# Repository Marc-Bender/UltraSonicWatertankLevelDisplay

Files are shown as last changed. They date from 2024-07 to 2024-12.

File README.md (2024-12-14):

# README

##Intended Usecase
Waterlevel display in multitank battey of tanks. Tanks are located in basement, sense device will be mounted on top of tanks far enough away from filling port. 
Thus no watertightness or waterresistance is implemented for any of the components.

## Design Features
Multiple Sensorboards "supported" by design (read Mistakes#J5 for more).
Elaborate Liter-age estimation algorithm by approximation of tank geometry with multiple boxes of varying area, spacing of estimation-box-area-entries parametrizable (1 global value)
Remaining Tankgeometry (Distance when full, distance when empty, number of tanks) parametrizable. 
Measurement sample averaging with parametrizable sample count for general stability, reproducability and compensation of effects of surface-waves while filling (effectiveness not proven)
Sleep modes for powersaving: between user interactions (deepest possible sleep mode), for time that display is supposed to be on (deepest sleep mode that can be left by timer)
Parametrization via UART with ready made tool (Open protocol)

## Operating instructions
Connect battery without pressing the front panel button --> normal startup procedure; system will perform one measurement cycle and show the results on the display
Connect battery with pressed front panel button --> boot into parametrization mode; leave via UART command or powercycle

## Basic-most Troubleshooting 
### "Display stays dark on button press"
Disassembly of sense device, check battery voltage -- system will not attempt any measurements below 7V
When Battery Voltage >7V attempt powercycle (battery disconnect-reconnect)

## Parametrization protocol
### UART Specifics
9600Baud, 8bits, 1 stop bit, no parity
### Leaving the parametrization session
send ":q" (without quotes)
### write a memory location 
send ":wXXYY" where XX is the address in MSB first and YY is the value in MSB first (both 16bit); device will respond with ":WXX00" where XX is that same address and 00 is padding data.
### read a memory location
analogous to write except ":r" is to be used instead of ":w"; data will be in last two response bytes in 16bit MSBFirst
### Memory Map
TankFullCM         | 0x0000 | 2bytes
TankEmptyCM        | 0x0002 | 2bytes
NumTanks           | 0x0004 | 1byte
AreaEntryCount     | 0x0005 | 1byte
AreaEntrySpacingCm | 0x0006 | 1byte
AveragingCount     | 0x0007 | 1byte
SensorType         | 0x0008 | 1byte (0: HC-SR04, 1:Grove)
AreaEntrySpaceStart| 0x000A | 2bytes per entry

## Power Figures
To be powered from a 9V Block Battery. Active current (w/ Display on, sensor not attached) is ~15mA. 
The MCU will be in sleep just about the entire time. The current transient for the MCU being active is assumed to be neglegdable.
The current transient by the sensor has not been determined. But the sensor is powered from IO Pins and normally unpowered thus not adding to the Iq.
The current consumption in sleep (Display off, sensor disconnected, MCU sleep) was in the noise of the multimeter (readings are typical at ~1mV across 10R shunt experimentally put in place instead of regulator; ~100uA)

## Hacking features
Default values for liter estimation algorithm when activated by define but not configured in EEPROM.
Define for circumventing the Battery voltage measurement evaluation -- effectively rendering the BatteryLowFault State inoperable/unreachable.

## Mistakes 

### Parametrization tool 

Somehow the parametrization did not work in the real usecase where the device is powered from a 9V battery; neither with connected gnd nor with connected 5V rail nor both connected (to the usb to serial brigde)
Parametrization also did not work no matter if the TX and RX lines are crossed or not. -- I did not feel like investing any time in this issue anymore, thus did not use the parametrization at all and hardcoded the tank geometry
Circumvent: recompile firmware with different values for each tank geometry or manually generate the eeprom file. 

### voltage measurement 

The battery voltage measurement is wildly off -- this may be down to the reference of the ADC (VCCA) not being measured in any way impacting the measured value...
Circumvent: none

### case design / Assembly design 

the screw holes for the display retainment screws should not have gone through the entire part. 
the Controller PCB should have had any mounting holes. 
The PCB Sandwich should be held in place on the button side as well in some way; solved by drilling through the PCB (somewhere in the gnd plane above the button) and into the frontplate then securing the pcb sandwich with 1 or 2 threads of a screw
The button actuator may collide with the PCB sandwich and should be reshaped.
The Parametrization header's 5V pin is obscured by the lower mounting hole of the display -> circumvent by snipping that off.

### Q5
Reverse voltage Protection "Diode" Transistor (Q5) did not work in my testing.
Circumvent by placing a ordinary diode between pins 1 and 2 of the footprint.

### U2
Was not available to me at the time of building and pinning is unlike 117 or 78xx series regulator thus the device may be a bad pick when a generic jellybean part would be wanted. 
There is no special reason to use this one. 
Circumvent by either buying appropriate part or replace with 7805 mounted in reverse (smaller footprint one will work as current consumption of MCU and display when active is ~15mA in my measurement thus anysize regulator will likely be enough)

### J1
/tRST is connected to MCU but /sRST would be the one to use with standard AVR JTAG pinout. 
Circumvent by either using SPI which is available on the Display header or by shorting the /tRST and /sRST pins together.

### U1
ATmega1284P was initially designed in as it happened to be in my junkbox... later replaced with ATmega324PB as a cheaper more than plenty replacement.
The ATmega324PB is not exactly pin compatible as the two (1284P) supply pins on the bottom edge (17, 18) are IO pins on the 324PB.
Circumvent: none
Fix: new layout or stick with original design MCU. 
Impact: none as long as the SW does not configure the two pins as outputs (which it should not -- by design)

### V0
V0 had been planned to be connected to resistor divider for contrast setting (that is switch-off-able). But fixed 1k pull down would be enough.
Circumvent by not placing R13, R14, R11, Q3 and instead placing R12 as ~500R and placing another ~500R between pins 2 and 3 of Q3 (slight cant).
alternatively only place R12 as 1k and bridge pins 2 and 3 of Q3

### J5 
Pinning of header for Grove Ultrasonic rangefinder module is completely messed up w/ regard to the module. 
Circumvent: use a crossover wireharnes and / or change the pinning in as far as possible (supply pins). Possibly bridge pin 3 and 4 on J5 to fix switched signal and NC pin. 
alternatively stick with HC-SR04 board instead. 
Firmware side of things has not been verified for Grove module at all thus it may require some hacking to get working. 

### Q4 
Technically working how ever not sufficent for turning off the display. The display module will get its power also over the data and control lines if not powered thus setting all data and control lines to input-no-pullup before turning off the display is required.
Circumvent: not needed -- already accounted for in Firmware. 

## Issues
### Parametrization tool communication (General)
Send commands multiple times until a) the display lights up [stop session command] or b) message counter in log window in bottom updates
### Parametrization tool connection
Start the sense device in parametrization mode.
Send the stop command from the tool until successfully left the session. 
Keep the Tool running and connected to the UART to USB adapter.
Restart the sense device in parametrization mode. 
The communciation should now work -- signs of a non working communication are UI buttons not changing their animated state.
### Parametrization best practices
Send a value
set a different value
Read back value --> the UI element for setting doubles for display and should change value to before set value.

Always leave the parametrization session by stop command when values have been changed in order for the write to peristant memory to happen.

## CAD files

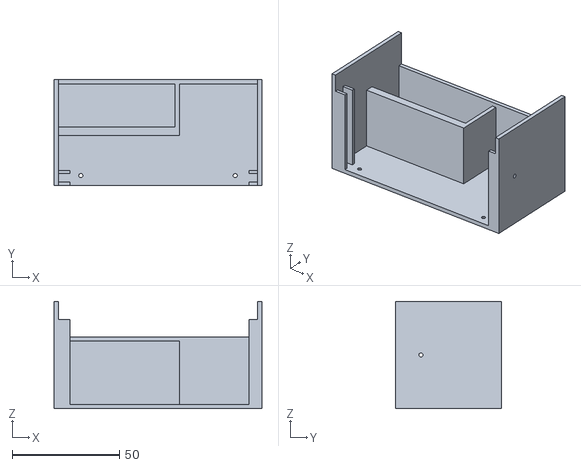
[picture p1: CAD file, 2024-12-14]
Mechanical Development/Box Upper.stl
97.0 x 49.2 x 50.0

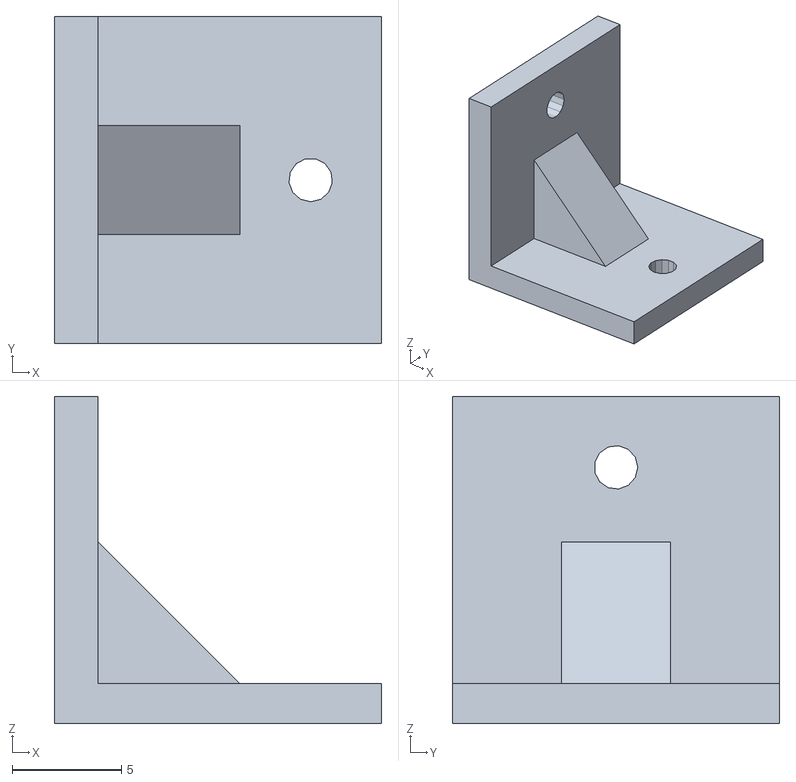
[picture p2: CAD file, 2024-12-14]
Mechanical Development/Bracket.stl
15.0 x 15.0 x 15.0

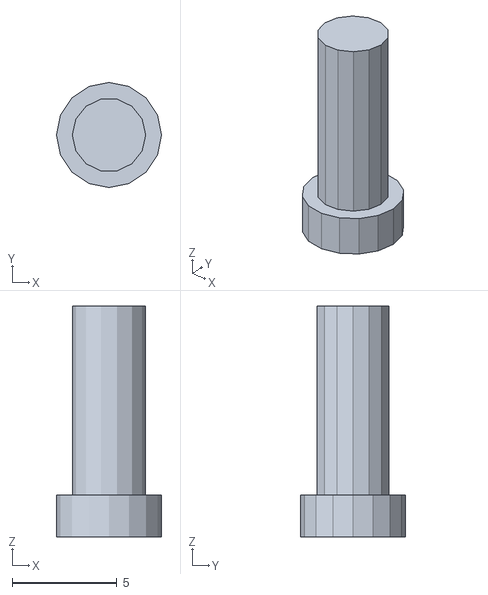
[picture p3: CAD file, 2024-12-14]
Mechanical Development/Drücker.stl
5.00 x 5.00 x 11.0

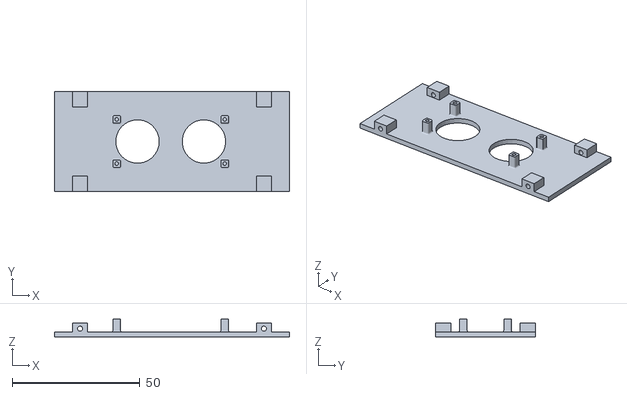
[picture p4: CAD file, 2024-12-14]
Mechanical Development/Box Lower.stl
92.0 x 39.0 x 7.00

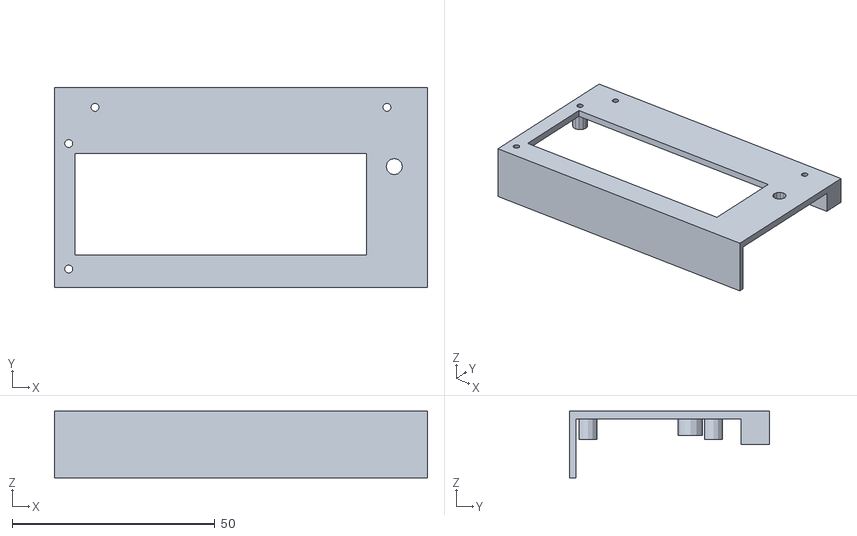
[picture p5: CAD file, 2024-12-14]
Mechanical Development/Frontplate.stl
92.0 x 49.2 x 16.5

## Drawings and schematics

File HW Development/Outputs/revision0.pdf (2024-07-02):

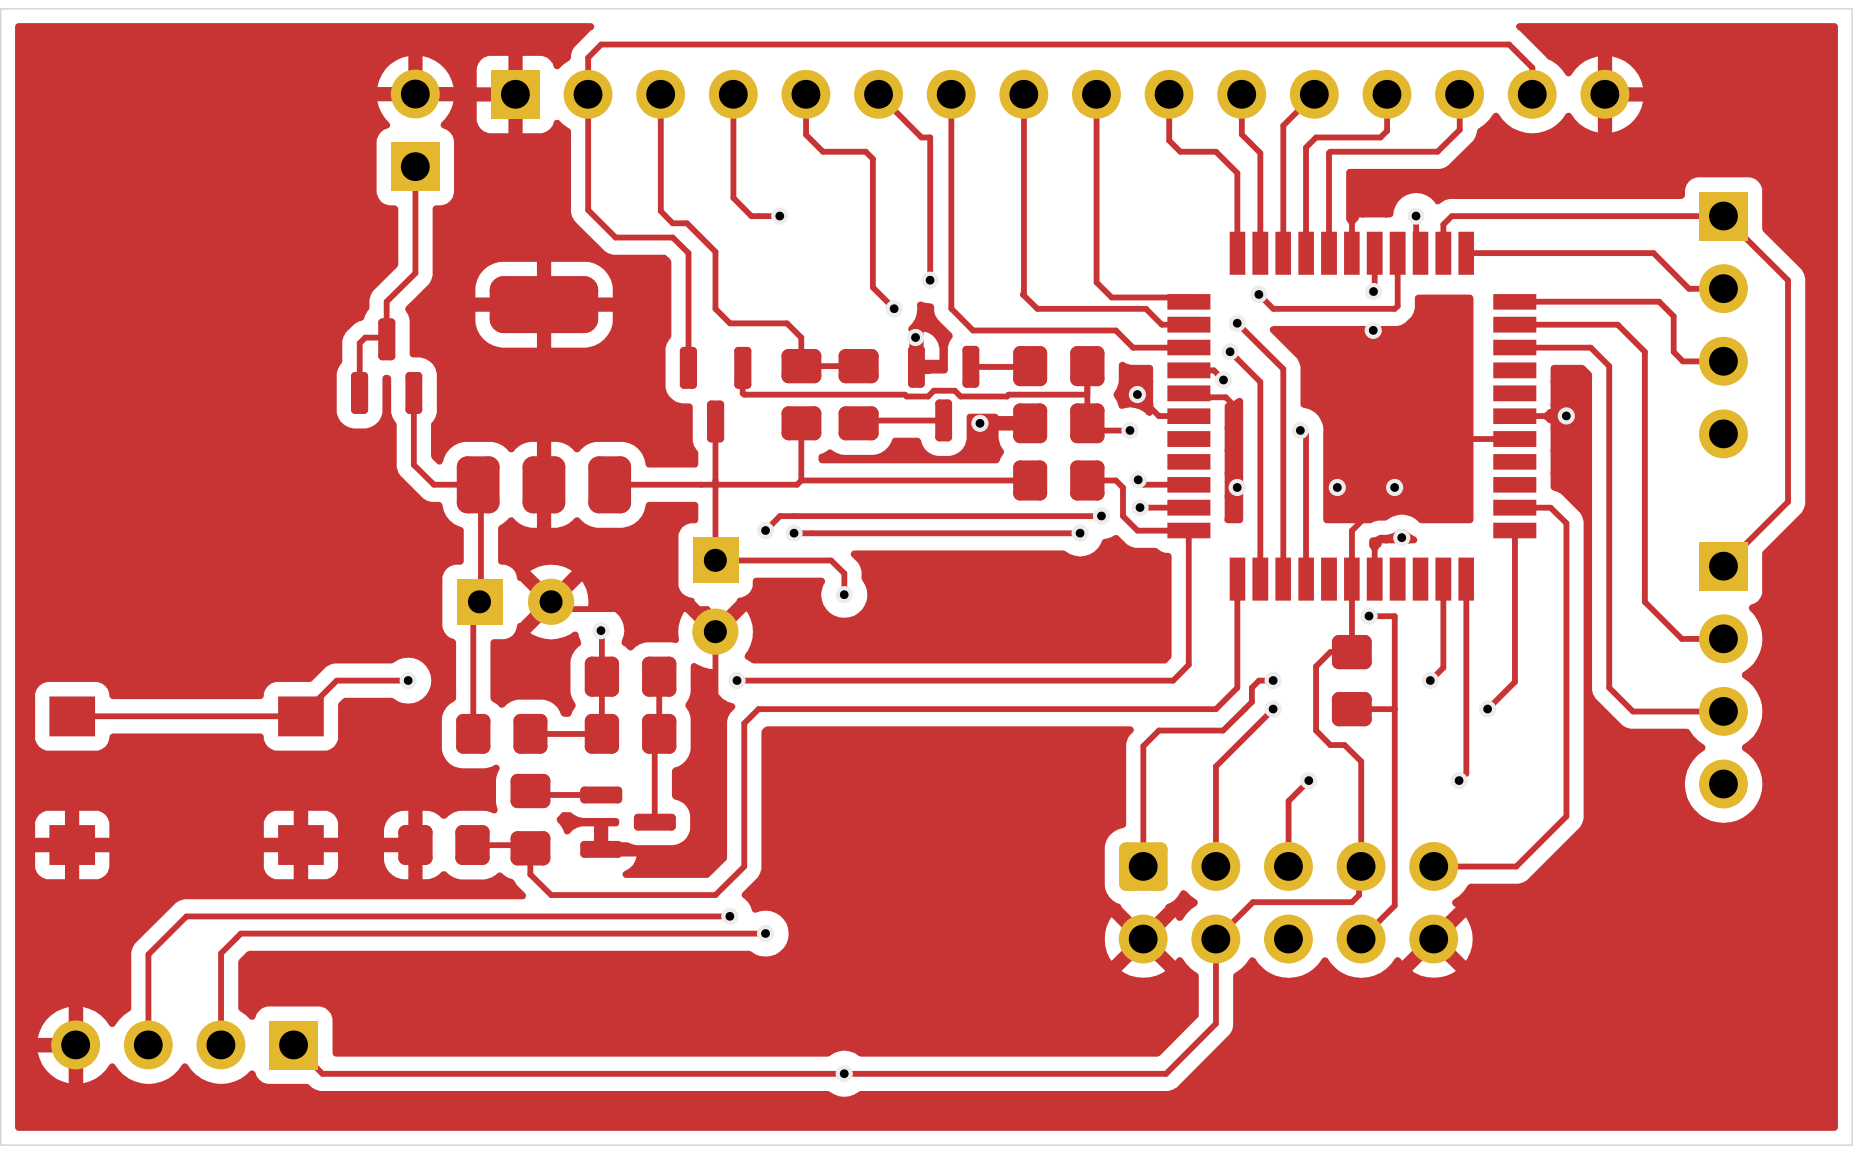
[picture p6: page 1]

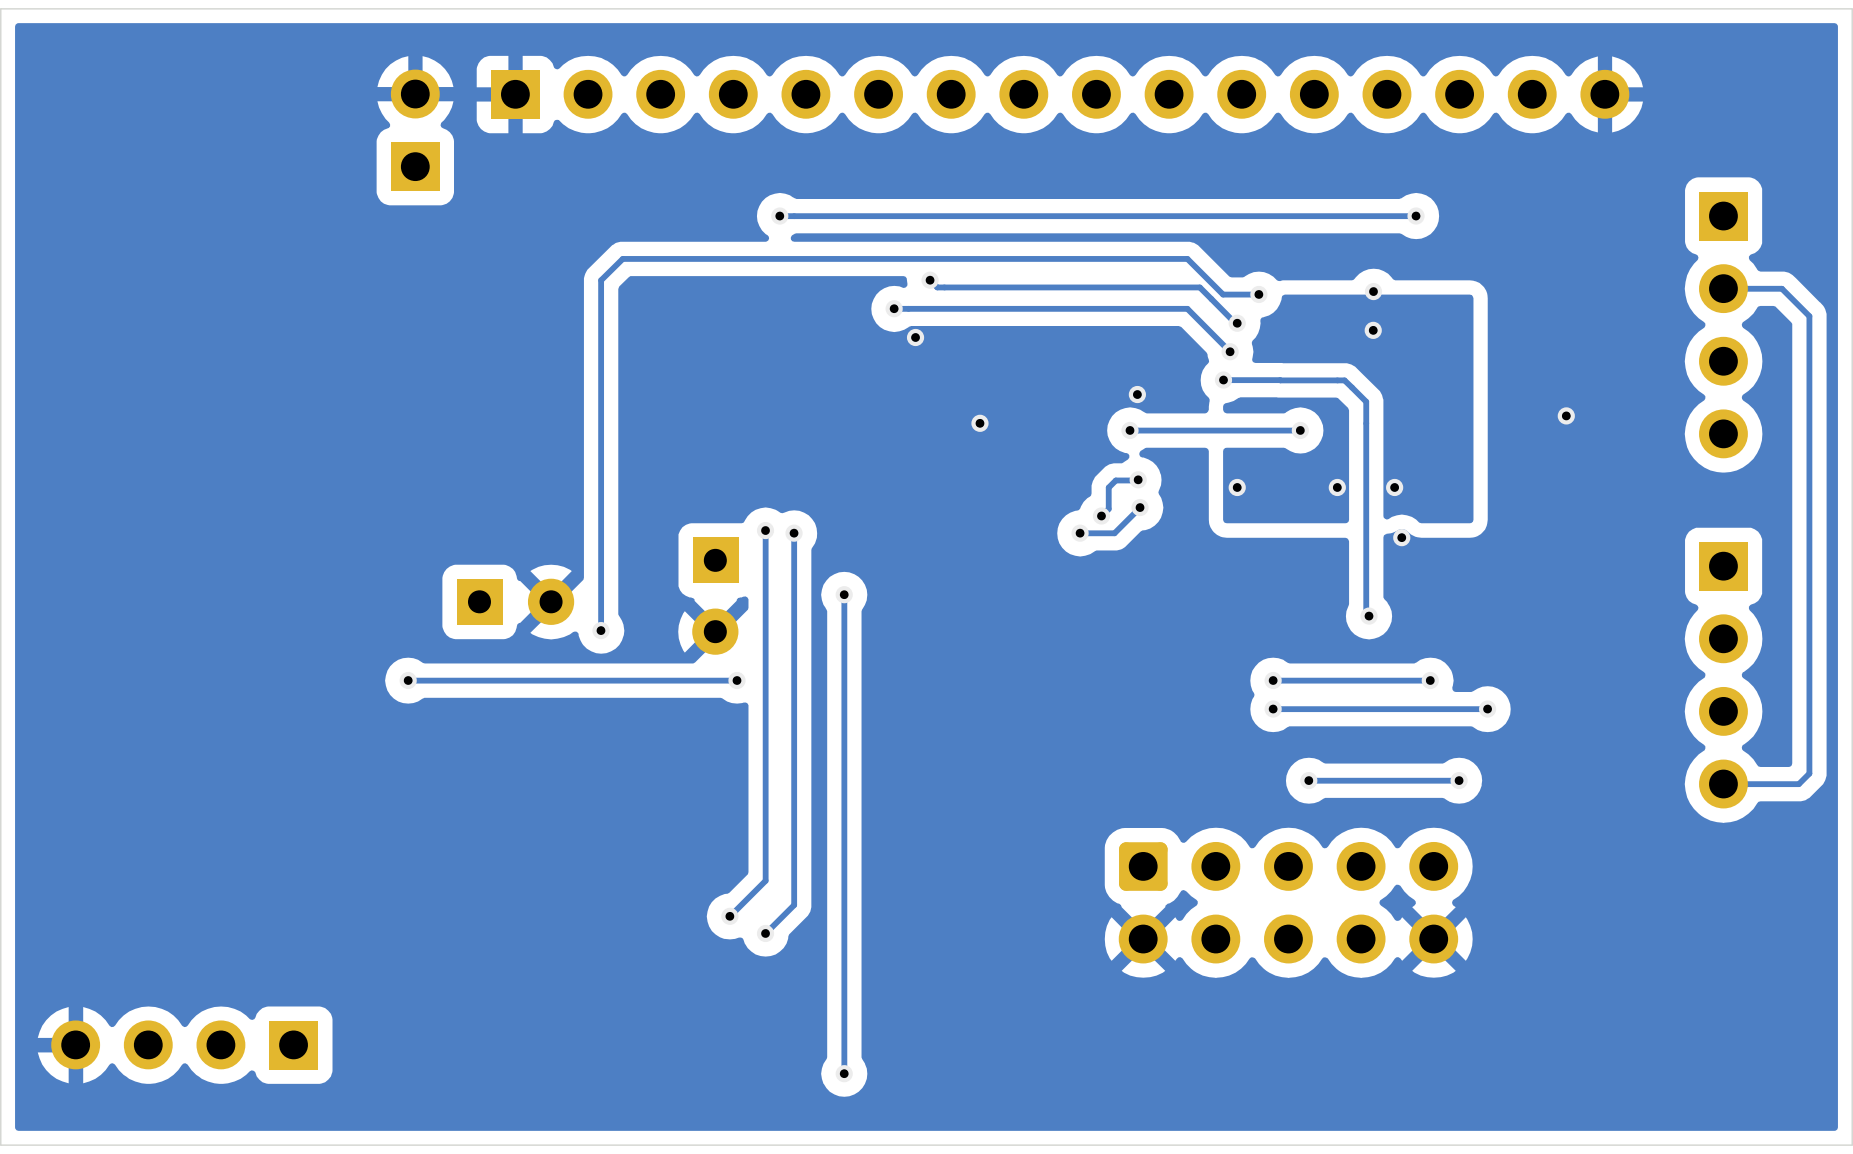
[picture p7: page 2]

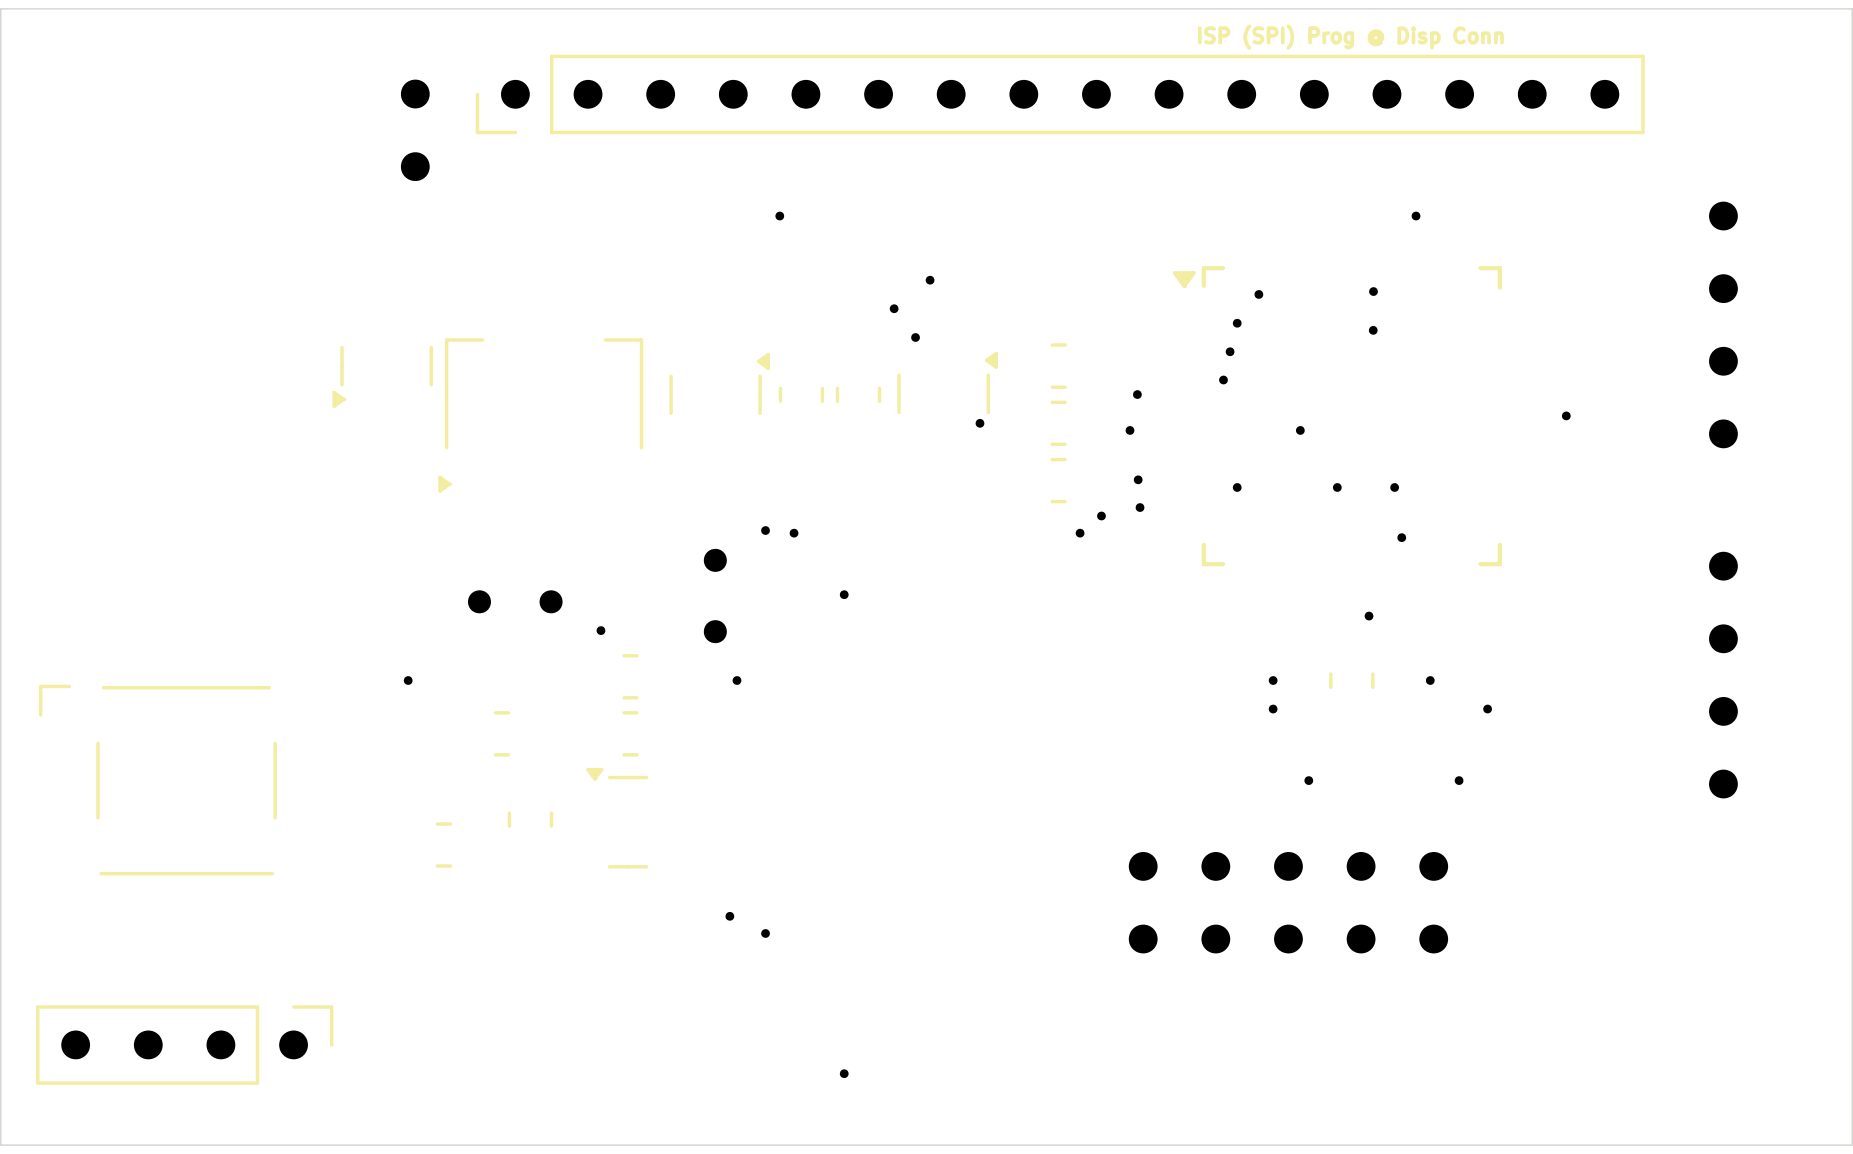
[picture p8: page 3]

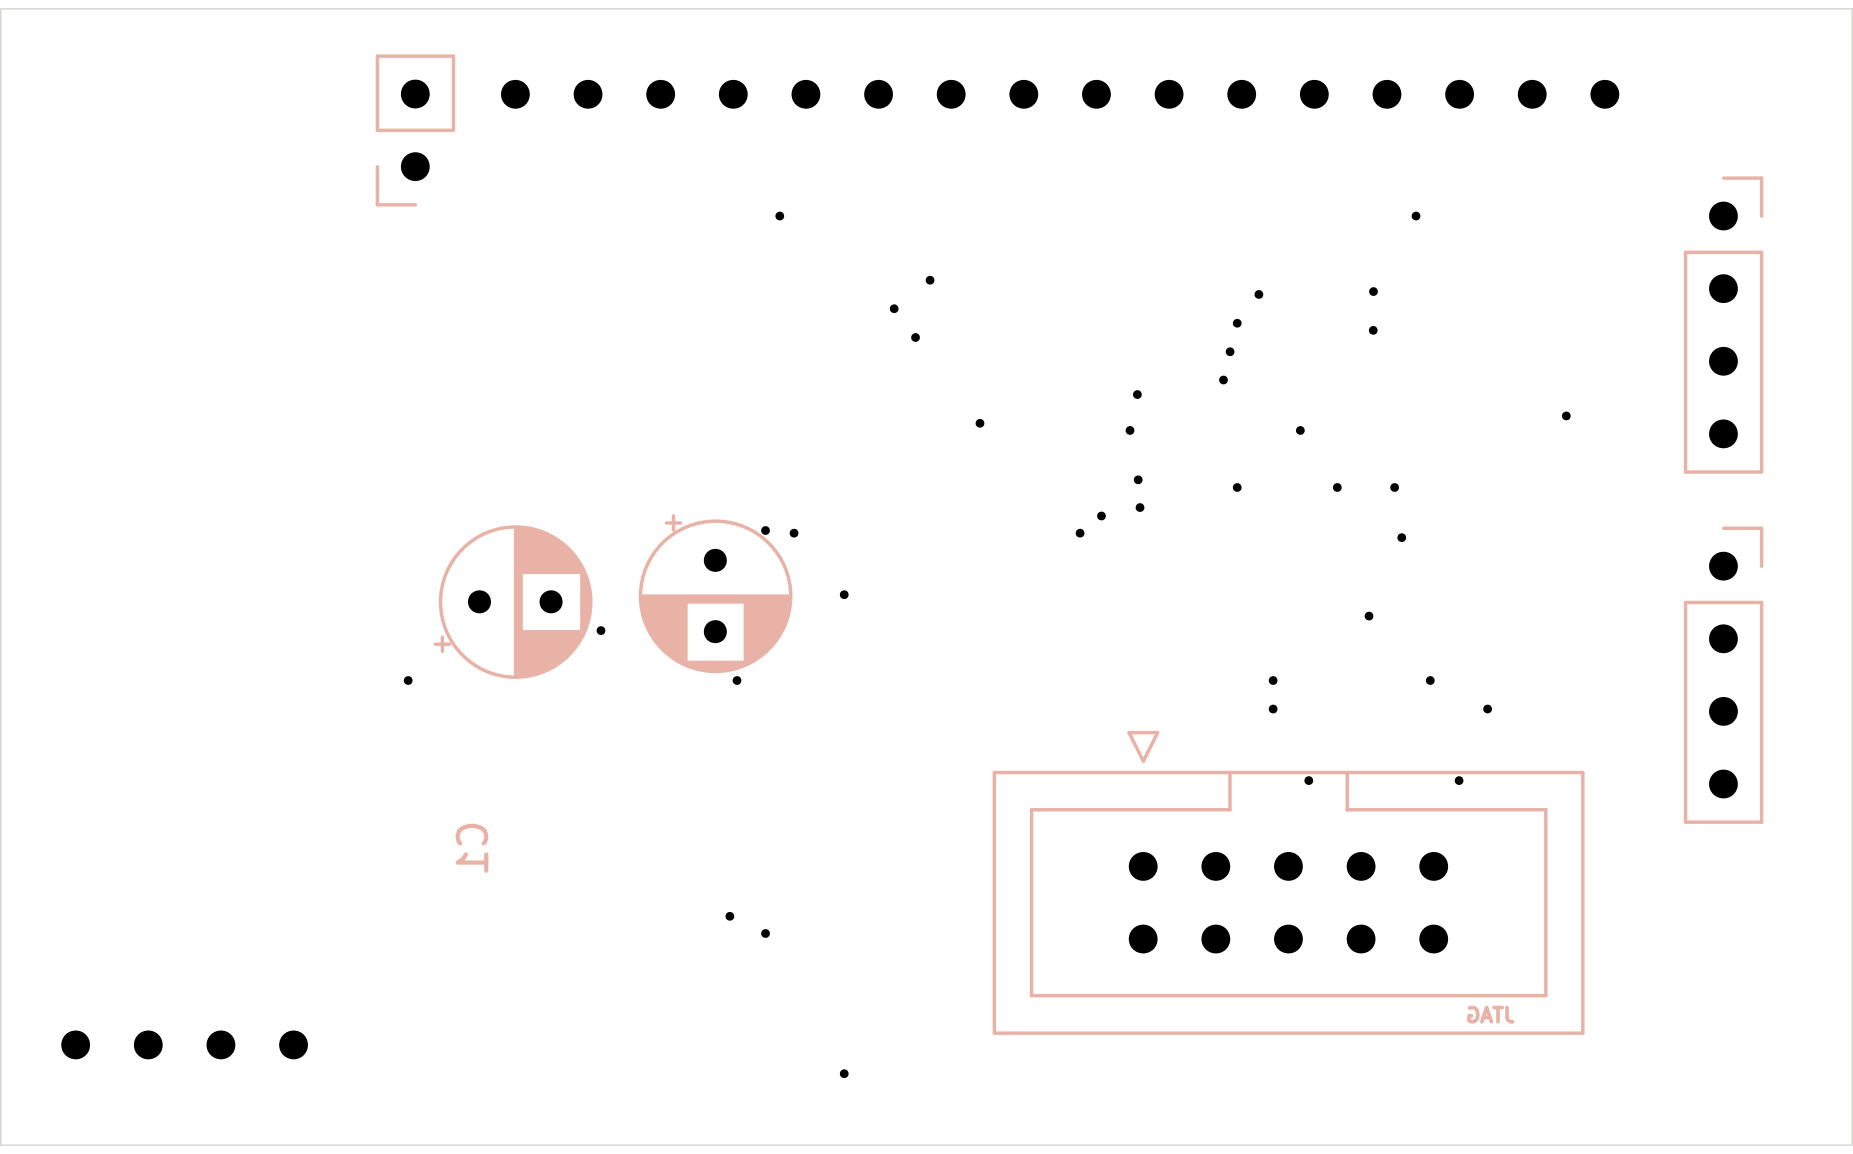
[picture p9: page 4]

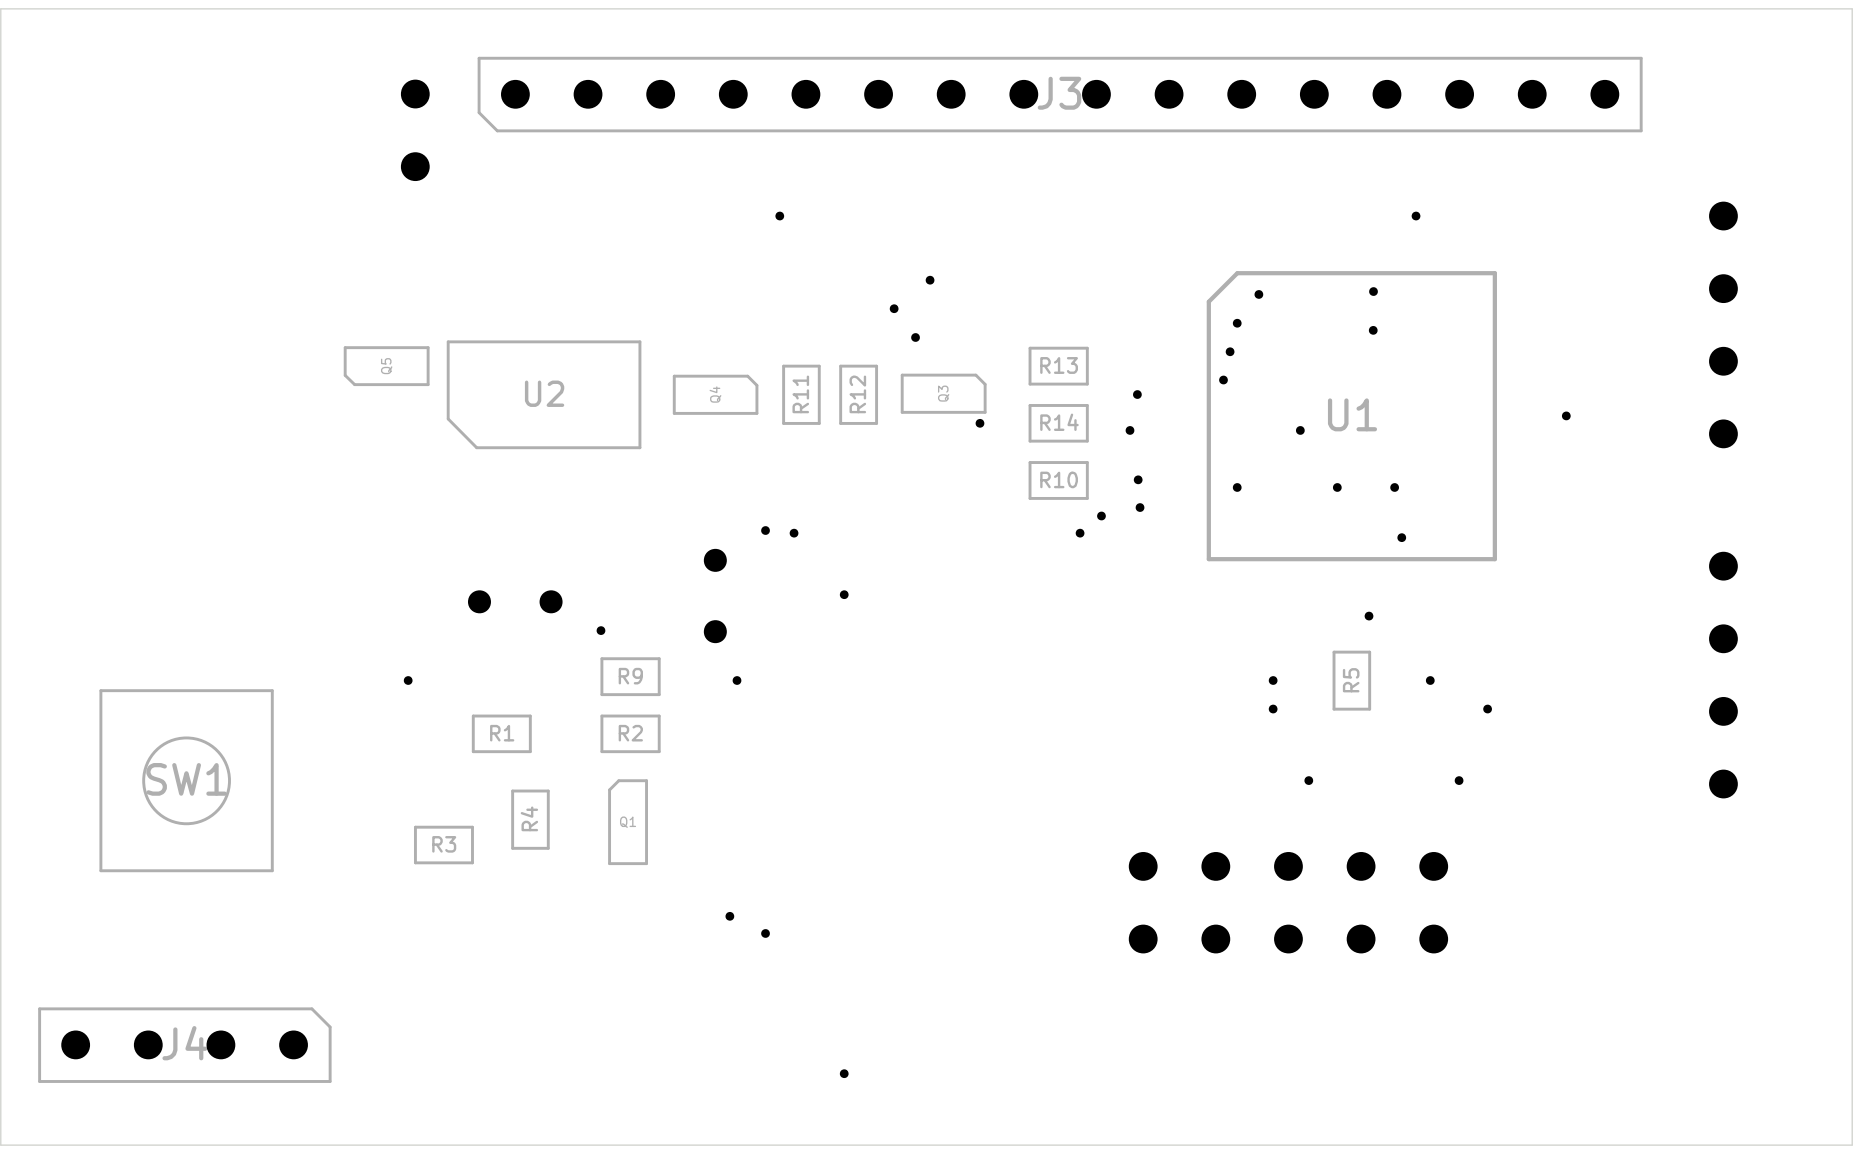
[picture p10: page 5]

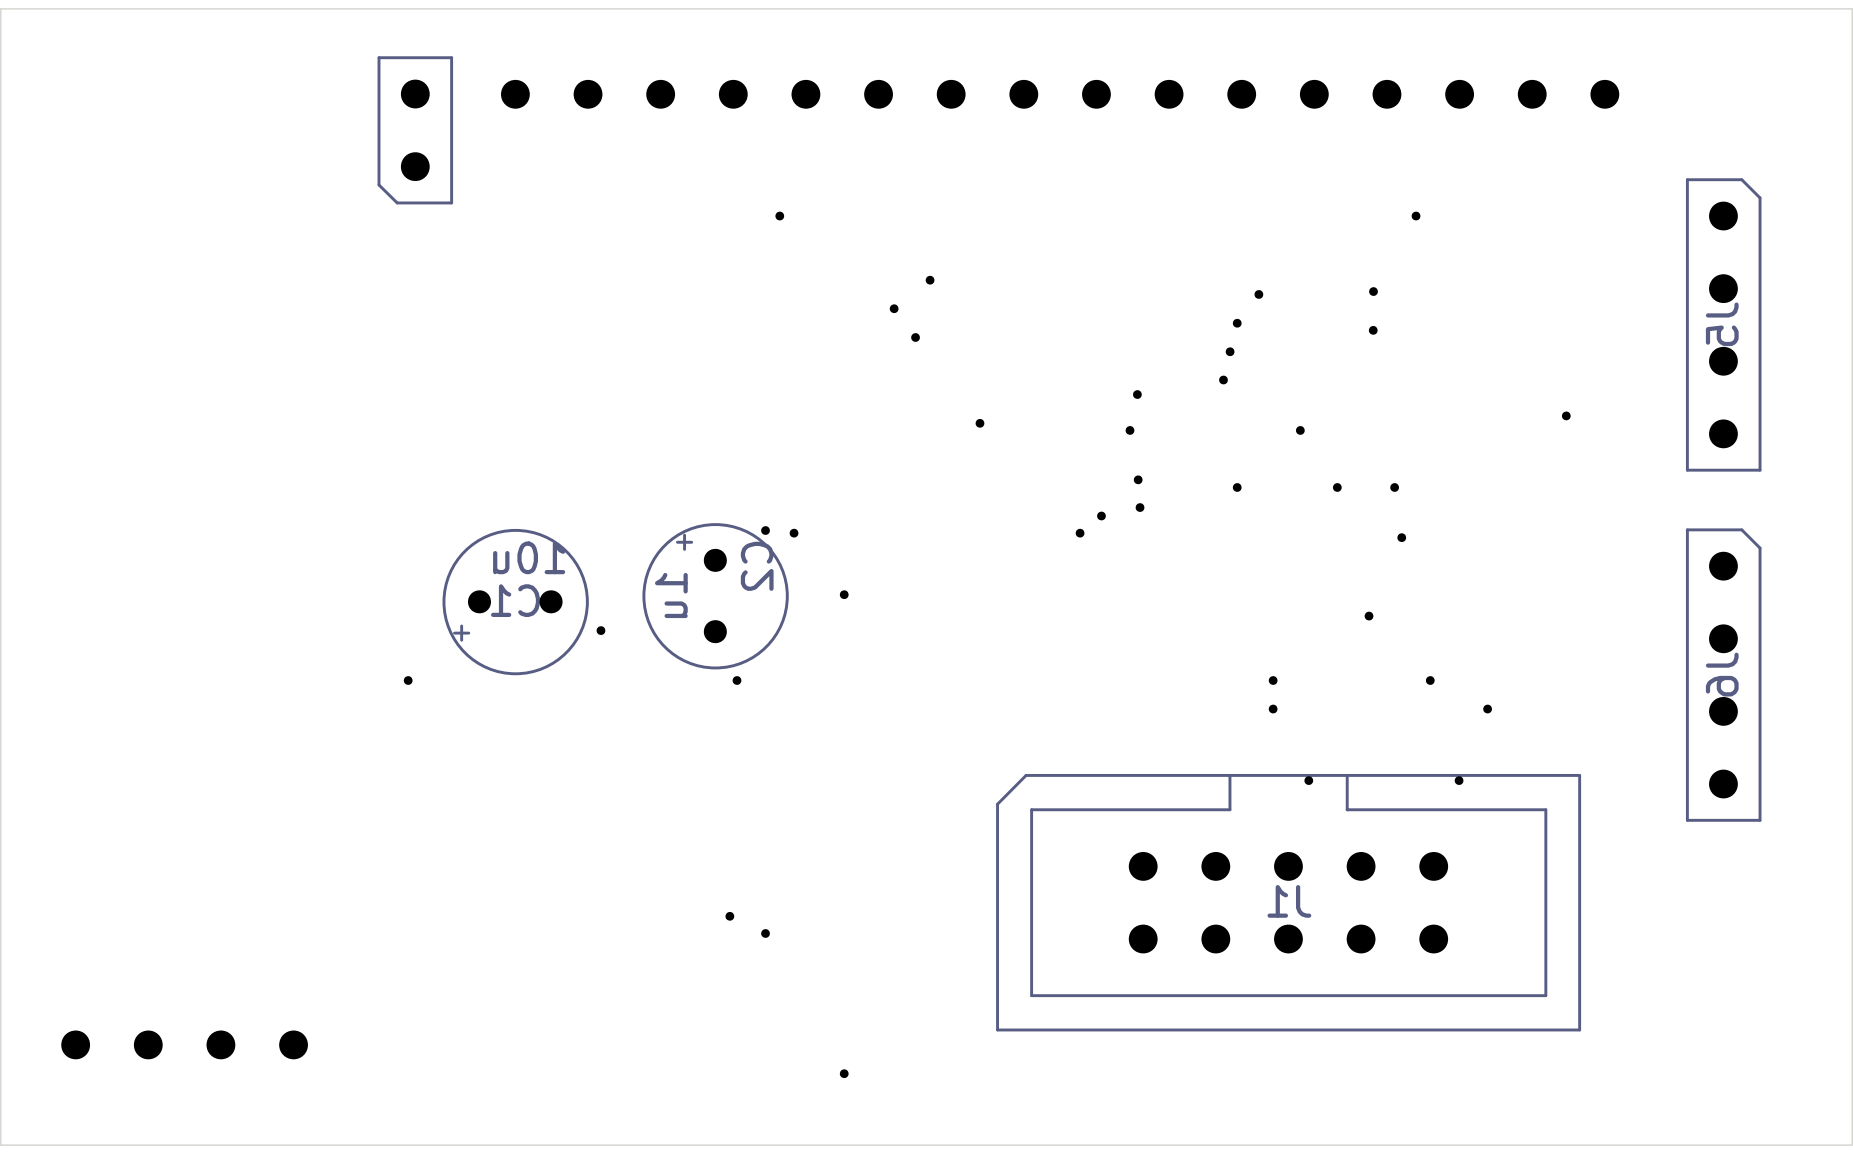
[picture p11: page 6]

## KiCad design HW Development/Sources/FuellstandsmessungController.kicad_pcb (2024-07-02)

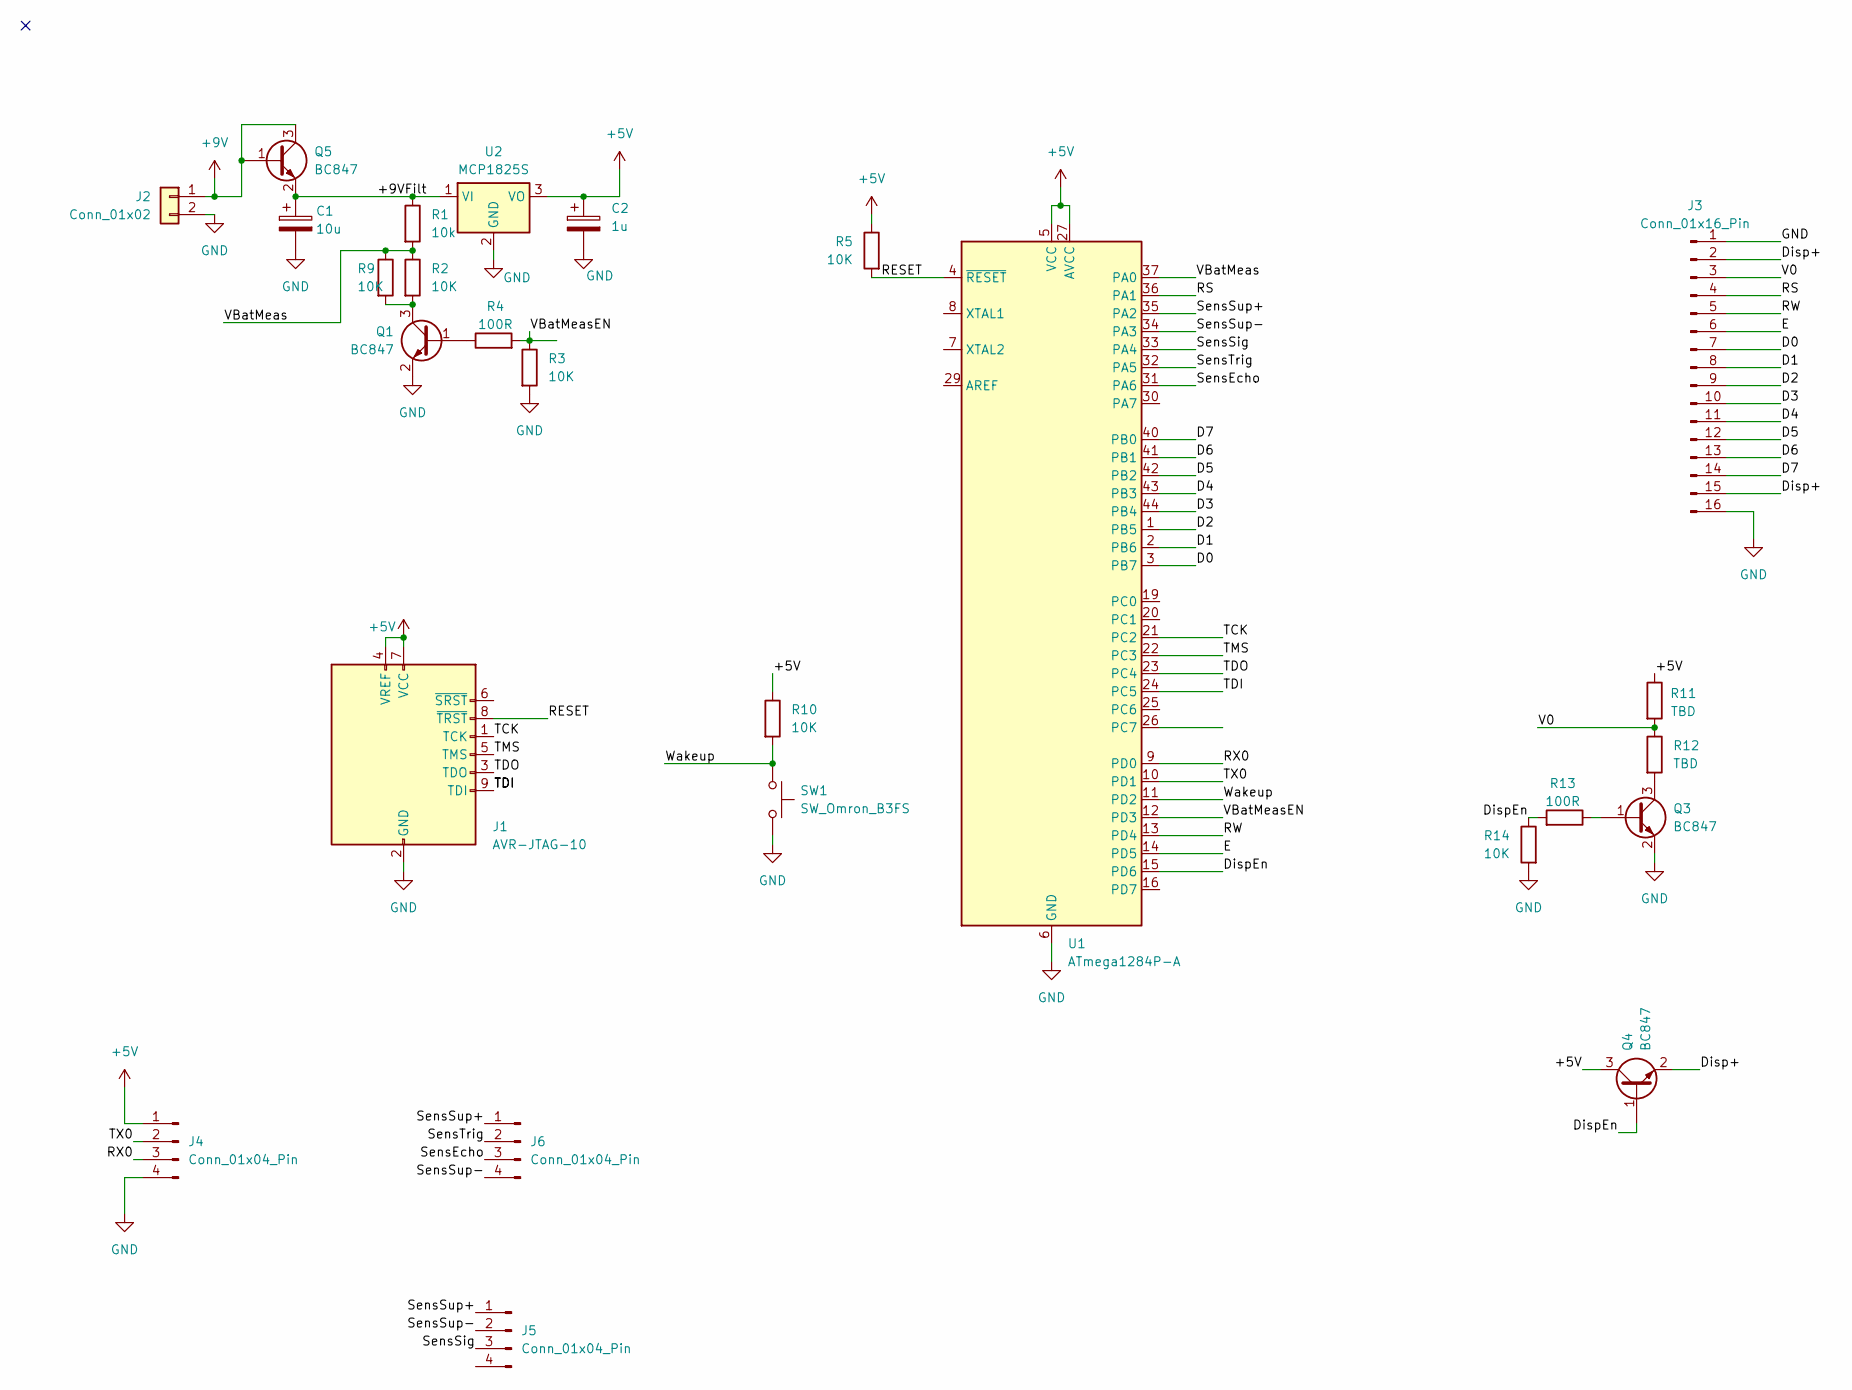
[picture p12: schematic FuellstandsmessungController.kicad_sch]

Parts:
C1: 10u; CP_Radial_D5.0mm_P2.50mm
C2: 1u; CP_Radial_D5.0mm_P2.50mm
J1: AVR-JTAG-10; IDC-Header_2x05_P2.54mm_Vertical
J2: Conn_01x02; PinHeader_1x02_P2.54mm_Vertical
J3: Conn_01x16_Pin; PinHeader_1x16_P2.54mm_Vertical
J4, J5, J6: Conn_01x04_Pin; PinHeader_1x04_P2.54mm_Vertical
Q1, Q3, Q4, Q5: BC847; SOT-23
R1: 10k; R_0805_2012Metric_Pad1.20x1.40mm_HandSolder
R2, R3, R5, R9, R10, R14: 10K; R_0805_2012Metric_Pad1.20x1.40mm_HandSolder
R4, R13: 100R; R_0805_2012Metric_Pad1.20x1.40mm_HandSolder
R11, R12: TBD; R_0805_2012Metric_Pad1.20x1.40mm_HandSolder
SW1: SW_Omron_B3FS; SW_SPST_Omron_B3FS-100xP
U1: ATmega1284P-A; TQFP-44_10x10mm_P0.8mm
U2: MCP1825S; SOT-223-3_TabPin2

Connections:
+5V: C2.1, J1.4 (VREF), J1.7 (VCC), J4.1, Q4.3 (C), R5.1, R10.1, R11.1, U1.5 (VCC), U1.17 (VCC), U1.27 (AVCC), U1.38 (VCC), U2.3 (VO)
+9V: J2.1, Q5.1 (B), Q5.3 (C)
/+9VFilt: C1.1, Q5.2 (E), R1.1, U2.1 (VI)
/D0: J3.7, U1.3 (PB7)
/D1: J3.8, U1.2 (PB6)
/D2: J3.9, U1.1 (PB5)
/D3: J3.10, U1.44 (PB4)
/D4: J3.11, U1.43 (PB3)
/D5: J3.12, U1.42 (PB2)
/D6: J3.13, U1.41 (PB1)
/D7: J3.14, U1.40 (PB0)
/Disp+: J3.2, J3.15, Q4.2 (E)
/DispEn: Q4.1 (B), R13.2, R14.1, U1.15 (PD6)
/E: J3.6, U1.14 (PD5)
/RESET: J1.8 (~TRST), R5.2, U1.4 (~RESET)
/RS: J3.4, U1.36 (PA1)
/RW: J3.5, U1.13 (PD4)
/RX0: J4.3, U1.9 (PD0)
/SensEcho: J6.3, U1.31 (PA6)
/SensSig: J5.3, U1.33 (PA4)
/SensSup+: J5.1, J6.1, U1.35 (PA2)
/SensSup-: J5.2, J6.4, U1.34 (PA3)
/SensTrig: J6.2, U1.32 (PA5)
/TCK: J1.1 (TCK), U1.21 (PC2)
/TDI: J1.9 (TDI), U1.24 (PC5)
/TDO: J1.3 (TDO), U1.23 (PC4)
/TMS: J1.5 (TMS), U1.22 (PC3)
/TX0: J4.2, U1.10 (PD1)
/V0: J3.3, R11.2, R12.1
/VBatMeas: R1.2, R2.1, R9.1, U1.37 (PA0)
/VBatMeasEN: R3.1, R4.2, U1.12 (PD3)
/Wakeup: R10.2, SW1.1, U1.11 (PD2)
GND: C1.2, C2.2, J1.2 (GND), J1.10 (GND), J2.2, J3.1, J3.16, J4.4, Q1.2 (E), Q3.2 (E), R3.2, R14.2, SW1.2, U1.6 (GND), U1.18 (GND), U1.28 (GND), U1.39 (GND), U2.2 (GND)
unnamed: Q1.1 (B), R4.1
unnamed: Q1.3 (C), R2.2, R9.2
unnamed: Q3.1 (B), R13.1
unnamed: Q3.3 (C), R12.2

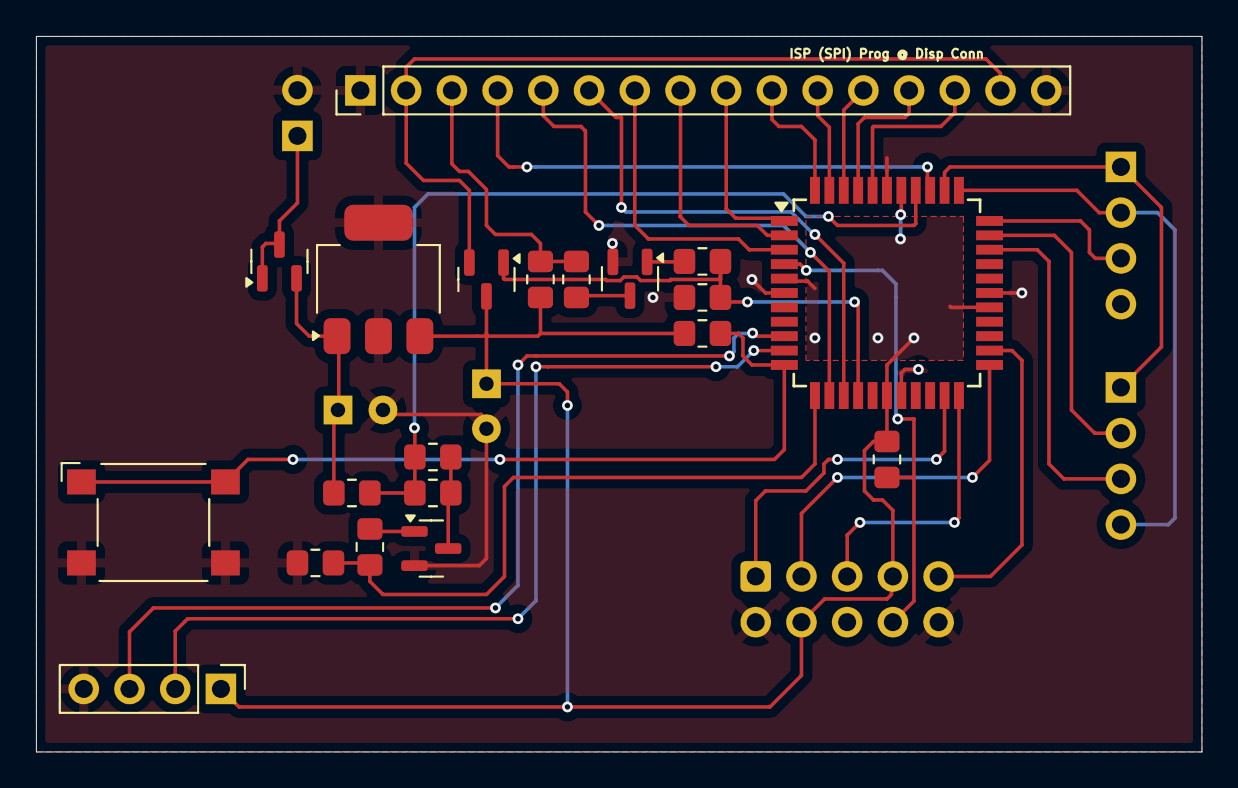
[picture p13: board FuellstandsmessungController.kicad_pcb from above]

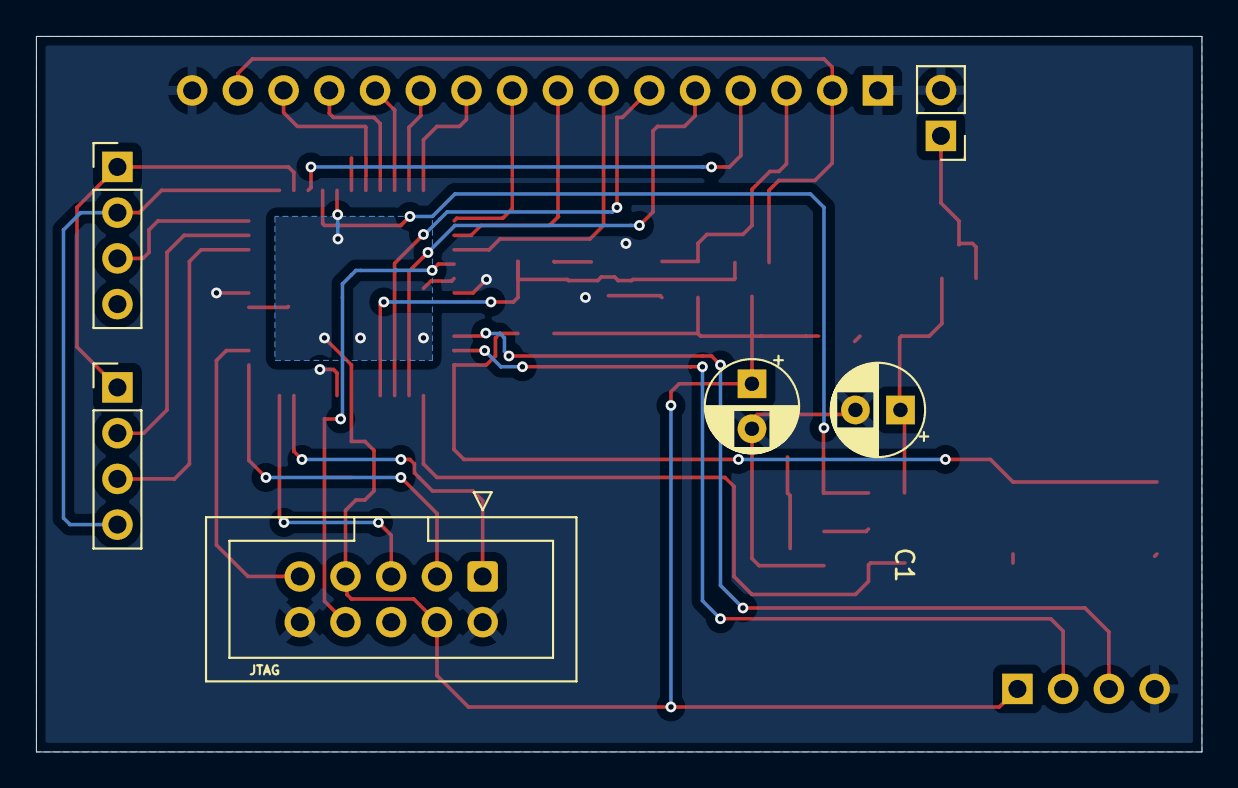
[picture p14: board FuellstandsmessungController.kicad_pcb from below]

Board: 2 copper layers, 64.8 x 39.8 mm, 26 parts (6 on the bottom side), 37 nets.

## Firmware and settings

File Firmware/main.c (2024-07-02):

/*
 * Fuellstandsmessung.c
 *
 * Created: 19.05.2024 14:26:16
 * Author : marc
 */ 

#include <avr/io.h>
#include "systemStates.h"
#include "gpio.h"
#include "uart.h"


int main(void)
{
    /* Replace with your application code */
	volatile const uint8_t mcusrold = MCUSR; // store the reset cause for the case that it needs to be evaluated (eg. during debugging)
	MCUSR = 0; // reset the reset cause flags as soon as possible to prevent getting stuck in a mode that can only be left by POR
    while (1) 
    {
		Appl_systemStateMachine_execute();
    }
}

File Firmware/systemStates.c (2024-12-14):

/*
 * systemStates.c
 *
 * Created: 19.05.2024 14:31:08
 *  Author: marc
 */ 

#include "systemStates.h"
#include "gpio.h"
#include "adc.h"
#include "eeprom.h"
#include "powerMgr.h"
#include "uart.h"
#include "display.h"
#include "measure.h"
#include "timer.h"
#include "exti.h"
#include <avr/sleep.h>
#include <avr/interrupt.h>
#include <avr/wdt.h>
#include <util/delay.h>
#include <stdlib.h>
#include <avr/interrupt.h>

#define IS_USB_POWERED (0)

#define SPEED_OF_SOUND_MM_PER_MILLI_SEC (343)
#define PARAMETRIZATION_REQUEST_SIZE (6) /*1 start character, 1 read write close connection indicator, 2 address bytes, 2 value bytes*/
#define PARAMETRIZATION_RESPONSE_SIZE (6) /*1 start character, 1 response code (read write positive, negative), 2 address bytes(echo), 2 value bytes*/

#define MIN(x,y) ((x)<(y)?(x):(y))
#define HIGHBYTE_OF(x) (((x)&0xFF00)>>8)
#define LOWBYTE_OF(x) (((x)&0x00FF))
						
volatile bool hasInterruptTriggered = false;
volatile systemState_t systemState = systemState_boot;
volatile systemState_t oldState = systemState_boot;


void Appl_systemStateMachine_execute(void)
{
	// actions to perfom in current state
	switch(systemState)
	{
		case systemState_boot:
		{
			// state action for boot state 
			PWR_disableAllPeripherals();
			PWR_enableUsedPeripherals();
			PWR_setNormalClockSpeed();
			wdt_disable();
			GPIO_init();
			EEPROM_init();
			GPIO_setVBatMeasEn_to(true);
			GPIO_setDispEn_to(false);
			USART_Init();
			USART_Transmit(":e",2);
			ADC_init();
			if(
				  (Meas_BatVoltage() <= 7000)
				&&(IS_USB_POWERED == 0)
			  )
			{
				// on low battery voltage switch to low battery voltage stage where essentially everything is turned off and forbidden.
				systemState = systemState_batLowFault;
			}
			else if(GPIO_getPin(Wakeup) == false)
			{
				// just booted and button is pressed .. transition into parametrization mode. 
				systemState = systemState_parametrization;
			}
			else
			{
				systemState = systemState_measure;
				//systemState = systemState_parametrization; // test only
			}

			// if else logic ensures that the boot state will only be traversed once
		}
		break;
		case systemState_measure:
		{
			// state action for the measure state --> the measure state likely is been reached because the system got woken up (less likely because of transition from boot state)
			// check the battery voltage before taking any fluid level measurement or doing any display business
			// if we just transitioned here from the boot state then the voltage measurement is redundant but will not harm too much
			PWR_enableUsedPeripherals(); // technically redundant when coming from boot state but absolutely required when entering via button press b/c timer and ADC are disabled and would not be enabled otherwise. causing the program to hang here after wakeup indefinitely
			ADC_init();
			uint16_t measuredBatVoltage = 0;

			#if IS_USB_POWERED == 0
				measuredBatVoltage = Meas_BatVoltage();
			#else
				measuredBatVoltage = 7543; // dummy value for testing
			#endif

			if(measuredBatVoltage <= 7000)
			{
				systemState = systemState_batLowFault;
			}
			else
			{
				// measurements are allowed --> perform them here
				ADC_disable(); // disable the ADC since the ADC is only needed for the battery voltage measurement and that has been performed already
				GPIO_setVBatMeasEn_to(false); // battery measurement already performed and voltage deemed sufficent for the measurement to be allowable... --> no need for measurement circuitry to be enabled anymore
				/*
				DDRA &= ~(1<<pins[SensEcho].pinnumber);
				*/
				/**
				PORTA |= (1<<pins[SensEcho].pinnumber); // input pullup 
				*/
				GPIO_setSensSupM_to(false); // negative supply to low aka gnd
				GPIO_setSensSupP_to(true); // positive supply to high aka vcc -> effectively provide power to the sensors
				_delay_ms(100); // allow the range finder to power up
				volatile uint32_t distanceAvg = 0;
				for(uint8_t i=0;i<EEPROM_averagingSampleCnt;i++)
				{
					volatile uint32_t durationInTicks = 0;
					switch(EEPROM_sensorType)
					{
						case sensorType_triggerEcho:
						{
							GPIO_setSensTrig_to(false); // generate the edge pattern needed for the trigger pin; timing taken from the arduino example for the hc-sr04 board; busy wait used since timing intervals are really short and do not really require timer based generation.
							_delay_us(2);
							GPIO_setSensTrig_to(true);
							_delay_us(50);
							GPIO_setSensTrig_to(false);
							while(GPIO_getPin(SensEcho) == false); // wait for the echo pin to go high because a falling edge means the echo has been received
							while(GPIO_getPin(SensEcho)==true)
							{
								durationInTicks++;
							}
							//measurement taken convert to distance next
						}
						break;
						case sensorType_grove:
						{
							pins[SensSig].isOutput = true; // initially used as trigger pin
							GPIO_SensSigPinReinit();
							GPIO_setSensSig_to(false); // generate the edge pattern needed for the trigger on the sig pin that serves double duty in the grove boards
							_delay_us(2);
							GPIO_setSensSig_to(true);
							_delay_us(10);
							GPIO_setSensSig_to(false);
							pins[SensSig].isOutput = false;
							GPIO_SensSigPinReinit();
							while(GPIO_getPin(SensSig) == false); // wait for the echo pin to go high because a falling edge means the echo has been received
							while(GPIO_getPin(SensSig)==true)
							{
								durationInTicks++;
							}
							//measurement taken convert to distance next
						}
						break;
						default:
						{
							// no such sensor;
							// nothing to do; maybe display warning in display
						}
						break;
					}
					_delay_ms(20); // to ensure the maximum sample rate of the module is never surpassed (50hz)
					volatile uint32_t durationInMicroseconds = durationInTicks * 104/10; // 8mhz internal rc osc means that one instruction takes 1/8 of a us... so conversion factor is >=8 value has been experimentally determined...
					volatile const uint32_t distanceCm = durationInMicroseconds * SPEED_OF_SOUND_MM_PER_MILLI_SEC / 2 / 10000;
					distanceAvg += distanceCm;
				}
				
				distanceAvg /= EEPROM_averagingSampleCnt; // divide the summed up distance samples to actually get the average distance to be displayed

				volatile uint16_t distanceHigherThanEmpty_cm = EEPROM_tankempty_cm > distanceAvg ? EEPROM_tankempty_cm - distanceAvg : 0; // empty tank should always be less than the measured distance otherwise the tank is "more than empty" so show an empty tank instead...
				volatile uint32_t cm3InTank = 0;
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

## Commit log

2024-07-02 initial commit for HW, embSW & pcSW
    [FuellstandsmessungController.kicad_pcb, FuellstandsmessungController.kicad_sch]
2024-07-02 Add extensive README and Mechanical design files
    [Box Lower.stl, Box Upper.stl, Frontplate.stl]
2024-09-13 update mechanical files
    [Box Lower.stl, Box Upper.stl, Drücker.stl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]
2024-12-14 redesign the entire casing to get away without having to use the retainment clips behind the PCB Sandwich (which turned out to be an assembly nightmare) also redesign the casing such that it actually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
    change the firmware such that the tank geometry of the tanks this was designed for is used by default b/c the parametrization did not work as intended.
    [Assembly.cfg, Box Lower.stl, Box Upper.stl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]
